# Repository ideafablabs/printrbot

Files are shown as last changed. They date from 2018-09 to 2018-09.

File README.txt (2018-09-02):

This is Idea Fab Labs running version of Marlin for the Printrbots. Also I have been changing the file
C:\Program Files (x86)\Arduino\hardware\teensy\avr\cores\usb_serial\usb_private.h to change the serial numbers so
these printers will show up as specific serial ports.

          .:                     :,                                          
,:::::::: ::`      :::                   :::                                          
,:::::::: ::`      :::                   :::                                          
.,,:::,,, ::`.:,   ... .. .:,     .:. ..`... ..`   ..   .:,    .. ::  .::,     .:,`   
   ,::    :::::::  ::, :::::::  `:::::::.,:: :::  ::: .::::::  ::::: ::::::  .::::::  
   ,::    :::::::: ::, :::::::: ::::::::.,:: :::  ::: :::,:::, ::::: ::::::, :::::::: 
   ,::    :::  ::: ::, :::  :::`::.  :::.,::  ::,`::`:::   ::: :::  `::,`   :::   ::: 
   ,::    ::.  ::: ::, ::`  :::.::    ::.,::  :::::: ::::::::: ::`   :::::: ::::::::: 
   ,::    ::.  ::: ::, ::`  :::.::    ::.,::  .::::: ::::::::: ::`    ::::::::::::::: 
   ,::    ::.  ::: ::, ::`  ::: ::: `:::.,::   ::::  :::`  ,,, ::`  .::  :::.::.  ,,, 
   ,::    ::.  ::: ::, ::`  ::: ::::::::.,::   ::::   :::::::` ::`   ::::::: :::::::. 
   ,::    ::.  ::: ::, ::`  :::  :::::::`,::    ::.    :::::`  ::`   ::::::   :::::.  
                                ::,  ,::                               ``             
                                ::::::::                                              
                                 ::::::                                               
                                  `,,`

http://www.thingiverse.com/thing:964701
Fan Shroud for E3D v6 Hotend on Printrbot Simple Metal with Secure Fit Spacer by tonyyoungblood is licensed under the Creative Commons - Attribution - Share Alike license.
http://creativecommons.org/licenses/by-sa/3.0/

# Summary

Here's a fan shroud for the E3D v6 hotend on a Printrbot Simple Metal printer. It's meant to be used in combination with this E3Dv6 spacer: http://www.thingiverse.com/thing:958450  

Because the hot end / spacer combination is shorter than the standard Printrbot hot ends, all other fan shrouds are too long. This fan shroud gets the air right where it needs to be when used in conjunction with the secure fit spacer.  

The holes are self-threading. No nuts required. The screws need to be at least 16mm long for the top two and at least 14mm long for the bottom two. You should have these available in your existing fan shroud or the extra screws that came with the Printrbot.  

Print with support structures. Recommended layer height: .2mm. I included a .2mm brim to counteract warping issues.  

Mount as shown in the pictures.  

Except for the hole spacings, which I pulled from Printrbot's fan shroud, this was designed from scratch. It was partially inspired by Simonwlchan's fan shroud, which is a great choice if you opt for the longer spacer. http://www.thingiverse.com/thing:957865

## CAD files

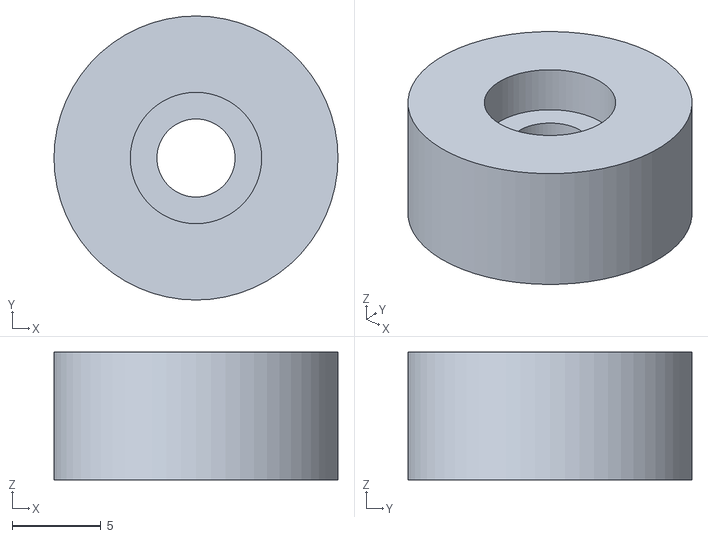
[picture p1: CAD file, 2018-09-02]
E3DPrintrbotSimpleMetalAdapter.stl
16.0 x 16.0 x 7.20

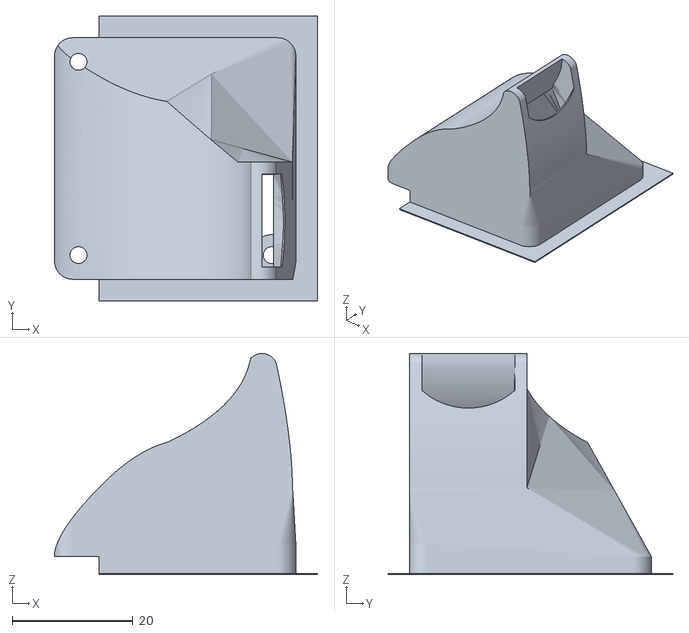
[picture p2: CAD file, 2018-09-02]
files/FanShroudE3Dv6PrintrbotSimpleMetal.stl
43.6 x 47.2 x 36.6

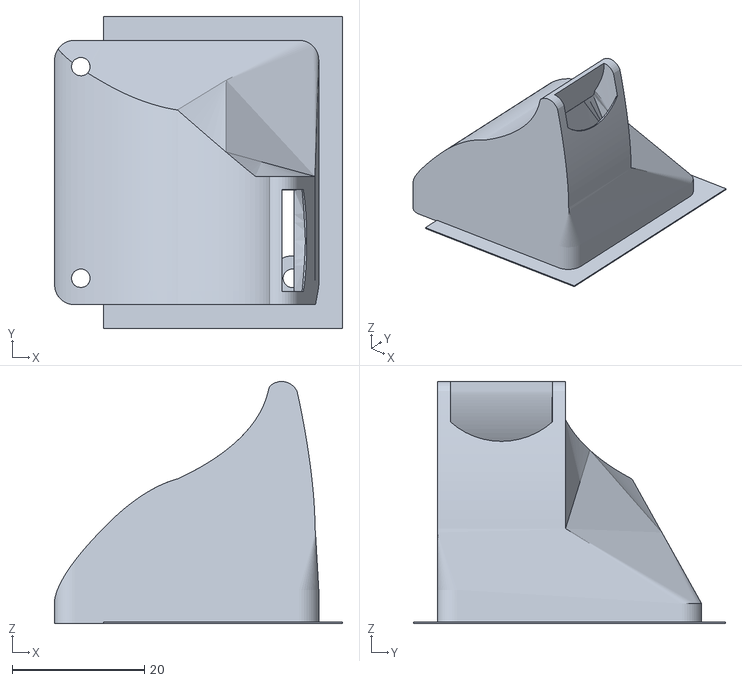
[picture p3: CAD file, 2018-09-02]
files/FanShroudE3Dv6PrintrbotSimpleMetal2.stl
43.6 x 47.2 x 36.6

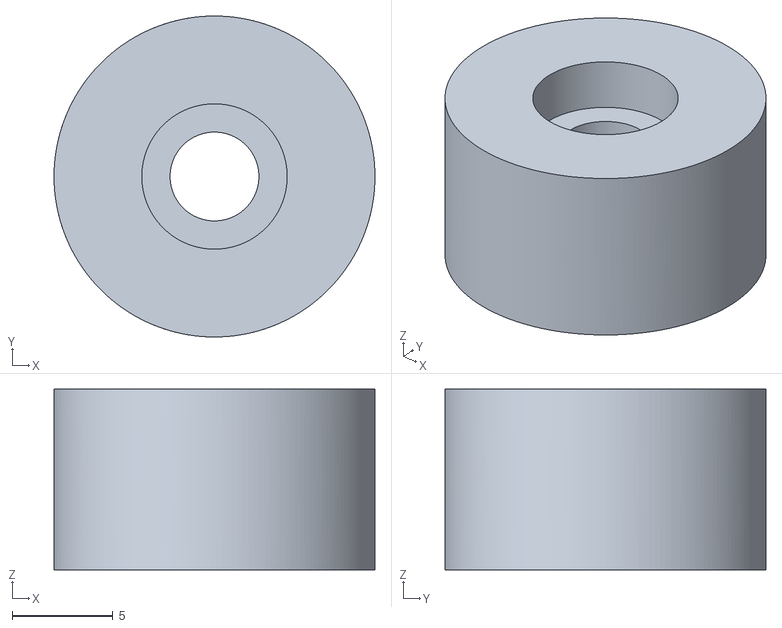
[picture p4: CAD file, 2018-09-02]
IFL_spacer.stl
15.9 x 15.9 x 8.95

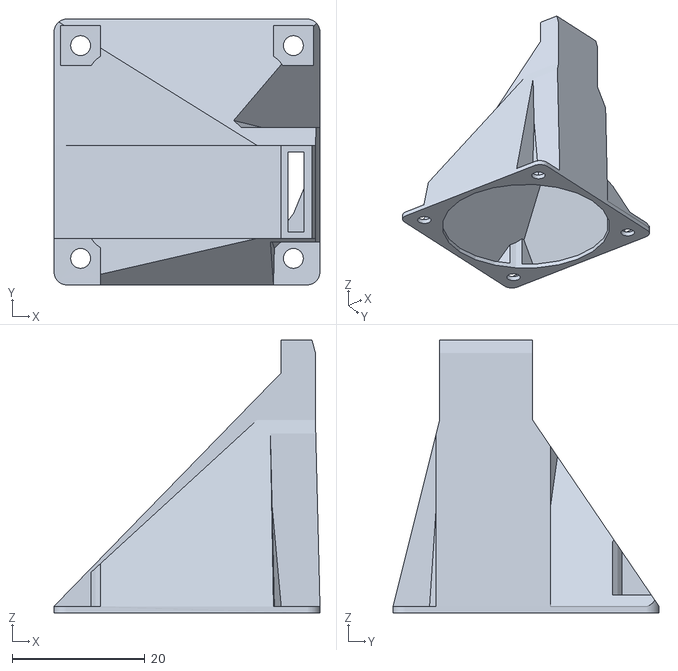
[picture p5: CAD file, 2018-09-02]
files/v6_PBM1403-E3Dv6_Fan_Shroud.stl
40.0 x 40.0 x 41.0

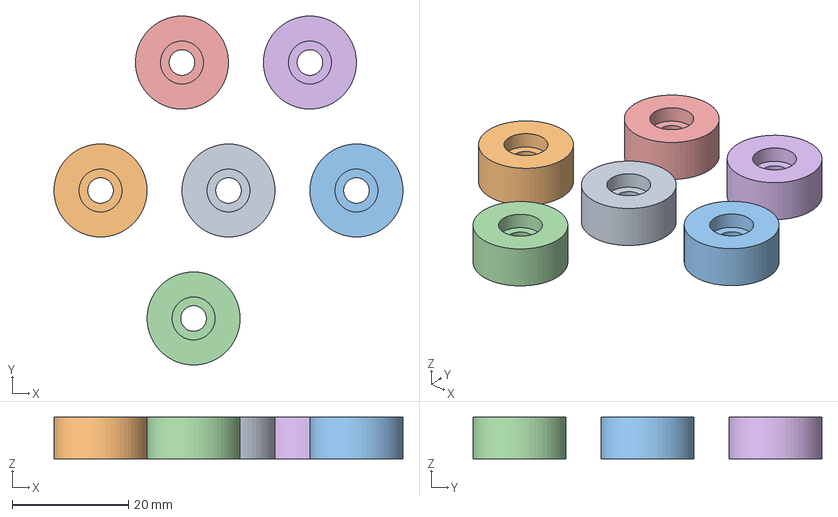
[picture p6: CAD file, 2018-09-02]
PS_E3DPrintrbotSimpleMetalAdapter.curaproject.3mf
60.0 x 60.0 x 7.20 mm

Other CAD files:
E3Dv6Spacer.ipt
files/FanShroudE3Dv6PrintrbotSimpleMetal.skp
files/FanShroudE3Dv6PrintrbotSimpleMetal2.skp

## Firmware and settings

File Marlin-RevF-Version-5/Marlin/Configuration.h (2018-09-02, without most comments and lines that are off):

#define CONFIGURATION_H
#define STRING_VERSION_CONFIG_H __DATE__ " " __TIME__ // build date and time
#define STRING_CONFIG_H_AUTHOR "(Michael Weiss, IFL Printrbot firmware)" // Who made the changes.
#define SERIAL_PORT 0
#define BAUDRATE 115200
#define MOTHERBOARD 84
#define CUSTOM_MENDEL_NAME "Printrbot"
#define EXTRUDERS 3
#define POWER_SUPPLY 1
#define TEMP_SENSOR_0 5
#define TEMP_SENSOR_1 1
#define TEMP_SENSOR_2 1
#define TEMP_SENSOR_BED 7
#define MAX_REDUNDANT_TEMP_SENSOR_DIFF 10
#define TEMP_RESIDENCY_TIME 10  // (seconds)
#define TEMP_HYSTERESIS 3       // (degC) range of +/- temperatures considered "close" to the target one
#define TEMP_WINDOW     1       // (degC) Window around target to start the residency timer x degC early.
#define HEATER_0_MINTEMP 5
#define HEATER_1_MINTEMP 5
#define HEATER_2_MINTEMP 5
#define BED_MINTEMP 5
#define HEATER_0_MAXTEMP 245
#define HEATER_1_MAXTEMP 275
#define HEATER_2_MAXTEMP 275
#define BED_MAXTEMP 150
#define PIDTEMP
#define BANG_MAX 255 // limits current to nozzle while in bang-bang mode; 255=full current
#define PID_MAX 255 // limits current to nozzle while PID is active (see PID_FUNCTIONAL_RANGE below); 255=full current
  #define PID_FUNCTIONAL_RANGE 10 // If the temperature difference between the target temperature and the actual temperature
  #define PID_INTEGRAL_DRIVE_MAX 255  //limit for the integral term
  #define K1 0.95 //smoothing factor within the PID
  #define PID_dT ((16.0 * 8.0)/(F_CPU / 64.0 / 256.0)) //sampling period of the temperature routine
    #define  DEFAULT_Kp 22.2
    #define  DEFAULT_Ki 1.08
    #define  DEFAULT_Kd 114
#define MAX_BED_POWER 255 // limits duty cycle to bed; 255=full current
#define PREVENT_DANGEROUS_EXTRUDE
#define PREVENT_LENGTHY_EXTRUDE
#define EXTRUDE_MINTEMP 150
#define EXTRUDE_MAXLENGTH (X_MAX_LENGTH+Y_MAX_LENGTH) //prevent extrusion of very large distances.
#define ENDSTOPPULLUPS // Comment this out (using // at the start of the line) to disable the endstop pullup resistors
  #define ENDSTOPPULLUP_XMAX
  #define ENDSTOPPULLUP_YMAX
  #define ENDSTOPPULLUP_ZMAX
  #define ENDSTOPPULLUP_XMIN
  #define ENDSTOPPULLUP_YMIN
  #define ENDSTOPPULLUP_ZMIN
const bool X_MIN_ENDSTOP_INVERTING = false; // set to true to invert the logic of the endstop.
const bool Y_MIN_ENDSTOP_INVERTING = false; // set to true to invert the logic of the endstop.
const bool Z_MIN_ENDSTOP_INVERTING = true; // set to true to invert the logic of the endstop.
const bool X_MAX_ENDSTOP_INVERTING = false; // set to true to invert the logic of the endstop.
const bool Y_MAX_ENDSTOP_INVERTING = false; // set to true to invert the logic of the endstop.
const bool Z_MAX_ENDSTOP_INVERTING = false; // set to true to invert the logic of the endstop.
#if defined(COREXY) && !defined(DISABLE_MAX_ENDSTOPS)
  #define DISABLE_MAX_ENDSTOPS
#endif
#define X_ENABLE_ON 0
#define Y_ENABLE_ON 0
#define Z_ENABLE_ON 0
#define E_ENABLE_ON 0 // For all extruders
#define DISABLE_X false
#define DISABLE_Y false
#define DISABLE_Z true
#define DISABLE_E false // For all extruders
#define INVERT_X_DIR true    // for Mendel set to false, for Orca set to true
#define INVERT_Y_DIR true    // for Mendel set to true, for Orca set to false
#define INVERT_Z_DIR true     // for Mendel set to false, for Orca set to true
#define INVERT_E0_DIR false   // for direct drive extruder v9 set to true, for geared extruder set to false
#define INVERT_E1_DIR false    // for direct drive extruder v9 set to true, for geared extruder set to false
#define INVERT_E2_DIR false   // for direct drive extruder v9 set to true, for geared extruder set to false
#define X_HOME_DIR -1
#define Y_HOME_DIR 1
#define Z_HOME_DIR -1
#define min_software_endstops true // If true, axis won't move to coordinates less than HOME_POS.
#define max_software_endstops true  // If true, axis won't move to coordinates greater than the defined lengths below.
#define X_MAX_POS_DEFAULT 152.4
#define X_MIN_POS_DEFAULT 0
#define Y_MAX_POS_DEFAULT 152.4
#define Y_MIN_POS_DEFAULT 0
#define Z_MAX_POS_DEFAULT 152.4
#define Z_MIN_POS_DEFAULT 0
#define X_MAX_LENGTH (base_max_pos[0] - base_min_pos[0])
#define Y_MAX_LENGTH (base_max_pos[1] - base_min_pos[1])
#define Z_MAX_LENGTH (base_max_pos[2] - base_min_pos[2])
#define ENABLE_AUTO_BED_LEVELING // Delete the comment to enable (remove // at the start of the line)
  #define LEFT_PROBE_BED_POSITION (bed_level_probe_offset[0] <= 10 ? 10 : bed_level_probe_offset[0])
  #define RIGHT_PROBE_BED_POSITION (bed_level_probe_offset[0] >= -10 ? X_MAX_LENGTH - 10 : X_MAX_LENGTH + bed_level_probe_offset[0])
  #define BACK_PROBE_BED_POSITION (bed_level_probe_offset[1] >= -10 ? Y_MAX_LENGTH - 10 : Y_MAX_LENGTH + bed_level_probe_offset[1])
  #define FRONT_PROBE_BED_POSITION (bed_level_probe_offset[1] <= 10 ? 10 : bed_level_probe_offset[1])
  #define X_PROBE_OFFSET_FROM_EXTRUDER_DEFAULT 25
  #define Y_PROBE_OFFSET_FROM_EXTRUDER_DEFAULT 0
  #define Z_PROBE_OFFSET_FROM_EXTRUDER_DEFAULT 0
  #define Z_RAISE_BEFORE_HOMING 4       // (in mm) Raise Z before homing (G28) for Probe Clearance.
  #define XY_TRAVEL_SPEED 5000         // X and Y axis travel speed between probes, in mm/min
  #define Z_RAISE_BEFORE_PROBING 4    //How much the extruder will be raised before traveling to the first probing point.
  #define Z_RAISE_BETWEEN_PROBINGS 5  //How much the extruder will be raised when traveling from between next probing points
  #define Z_SAFE_HOMING   // This feature is meant to avoid Z homing with probe outside the bed area.
    #define Z_SAFE_HOMING_X_POINT (X_MAX_LENGTH/2)    // X point for Z homing when homing all axis (G28)
    #define Z_SAFE_HOMING_Y_POINT (Y_MAX_LENGTH/2)    // Y point for Z homing when homing all axis (G28)
  #define ACCURATE_BED_LEVELING
    #define ACCURATE_BED_LEVELING_POINTS 3
#define MANUAL_X_HOME_POS 0
#define MANUAL_Y_HOME_POS 0
#define MANUAL_Z_HOME_POS 0
#define NUM_AXIS 4 // The axis order in all axis related arrays is X, Y, Z, E
#define HOMING_FEEDRATE {50*60, 50*60, 4*60, 0}  // set the homing speeds (mm/min)
#define DEFAULT_AXIS_STEPS_PER_UNIT   {80,80,2020,96}
#define DEFAULT_MAX_FEEDRATE          {125, 125, 5, 14}    // (mm/sec)
#define DEFAULT_MAX_ACCELERATION      {2000,2000,30,10000}    // X, Y, Z, E maximum start speed for accelerated moves. E default values are good for skeinforge 40+, for older versions raise them a lot.
#define DEFAULT_ACCELERATION          3000    // X, Y, Z and E max acceleration in mm/s^2 for printing moves
#define DEFAULT_RETRACT_ACCELERATION  3000   // X, Y, Z and E max acceleration in mm/s^2 for retracts
#define DEFAULT_XYJERK                20.0    // (mm/sec)
#define DEFAULT_ZJERK                 0.4     // (mm/sec)
#define DEFAULT_EJERK                 5.0    // (mm/sec)
#define EEPROM_SETTINGS
#define EEPROM_CHITCHAT
#define PLA_PREHEAT_HOTEND_TEMP 200
#define PLA_PREHEAT_HPB_TEMP 45
#define PLA_PREHEAT_FAN_SPEED 255   // Insert Value between 0 and 255
#define ABS_PREHEAT_HOTEND_TEMP 240
#define ABS_PREHEAT_HPB_TEMP 100
#define ABS_PREHEAT_FAN_SPEED 255   // Insert Value between 0 and 255
#define SDSUPPORT // Enable SD Card Support in Hardware Console
#define NEWPANEL
#define DISABLE_LCD_MOTION_MENU
#define DISABLE_PREHEAT_MENU
#define SOFT_PWM_SCALE 0
#include "Configuration_adv.h"
#include "thermistortables.h"

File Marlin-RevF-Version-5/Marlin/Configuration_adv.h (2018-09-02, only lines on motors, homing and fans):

#define CONTROLLERFAN_PIN -1 //Pin used for the fan to cool controller (-1 to disable)
#define EXTRUDER_0_AUTO_FAN_PIN   44
#define EXTRUDER_1_AUTO_FAN_PIN   -1
#define EXTRUDER_2_AUTO_FAN_PIN   -1
#define ENDSTOPS_ONLY_FOR_HOMING // If defined the endstops will only be used for homing
#define X_HOME_RETRACT_MM 5
#define Y_HOME_RETRACT_MM 5
#define Z_HOME_RETRACT_MM 1
#define MICROSTEP1 LOW,LOW
#define MICROSTEP2 HIGH,LOW
#define MICROSTEP4 LOW,HIGH
#define MICROSTEP8 HIGH,HIGH
#define MICROSTEP16 HIGH,HIGH
#define MICROSTEP_MODES {16,16,16,16,16} // [1,2,4,8,16]
#define DIGIPOT_MOTOR_CURRENT {135,135,135,135,135} // Values 0-255 (RAMBO 135 = ~0.75A, 185 = ~1A)

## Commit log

2018-09-02 This is the commit of the Printrbot Marlin code and other files for Idea Fab Labs
    [Configuration.h, Configuration_adv.h, E3DPrintrbotSimpleMetalAdapter.stl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]
2018-09-06 basic settings for .3 layer printrbot simple with an E3D hotend
2018-09-06 Here is a profile for our printrbots with the E3D hotend
